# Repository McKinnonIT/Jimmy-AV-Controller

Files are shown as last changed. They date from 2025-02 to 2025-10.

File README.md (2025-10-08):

# Jimmy AV Controller

## 🧩 Project Overview  
The Jimmy AV Controller is an open, customizable solution for projector and AV control over RS232. It is designed to address the limitations of existing commercial systems—closed ecosystems, high costs, poor interfaces, and no easy way to monitor usage and automate groups of projectors & TVs.

It’s designed for use in classrooms, conference rooms, and anywhere you want RS232 control over AV equipment.  
With touchscreen ESP32 boards like the JC2432W328 (capacitive) and 2432S028R (resistive), which support native LVGL in ESPHome, we built a customizable, user-friendly control panel that integrates easily with ESPHome and Home Assistant.  
We chose ESPHome for its popularity and maintainability, with many examples and community support already available.

<p align="center">
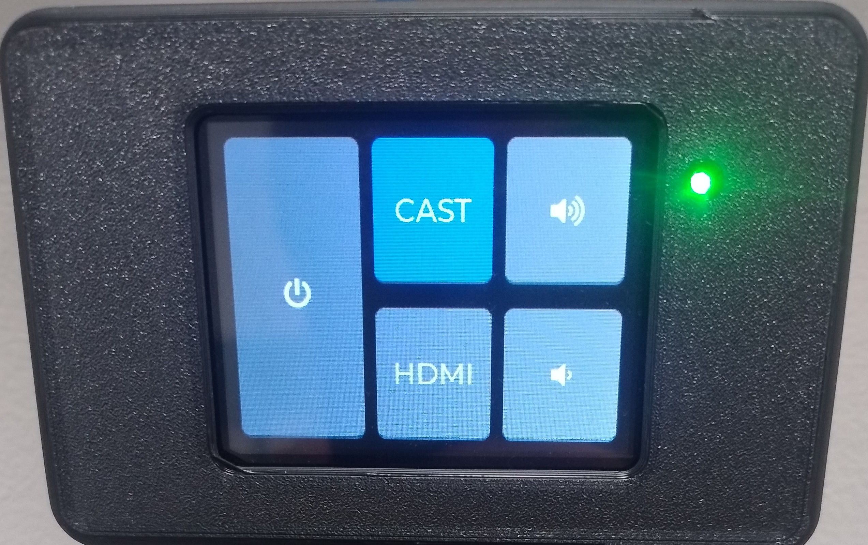
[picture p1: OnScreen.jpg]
  
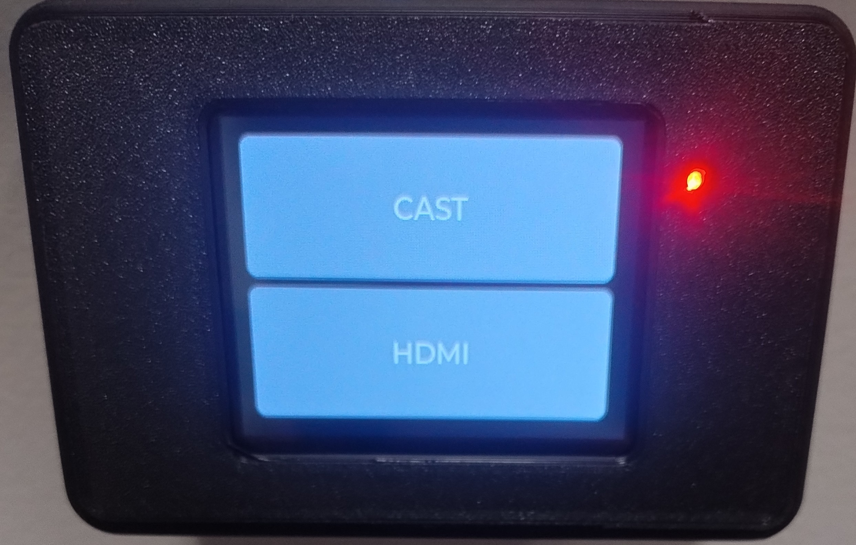
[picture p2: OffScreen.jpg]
  
</p>

## 🧠 How it works

The Jimmy AV Control System uses an ESP32 touchscreen panel to send RS232 commands to AV gear, integrating seamlessly with ESPHome and Home Assistant for easy automation and monitoring.

At its core, the system includes:
- ESP32 touchscreen (capacitive JC2432W328 or resistive 2432S028R) flashed with ESPHome
- LVGL customisable GUI
- 3D-printed wall plate & breakout box for secure mounting  
- RS232 to TTL UART breakout box  
- RJ45 Ethernet cables to connect breakout box to wall plate touchscreen  
- Generic DC power supply  

Using the ESPHome Web Flasher makes setup simple.

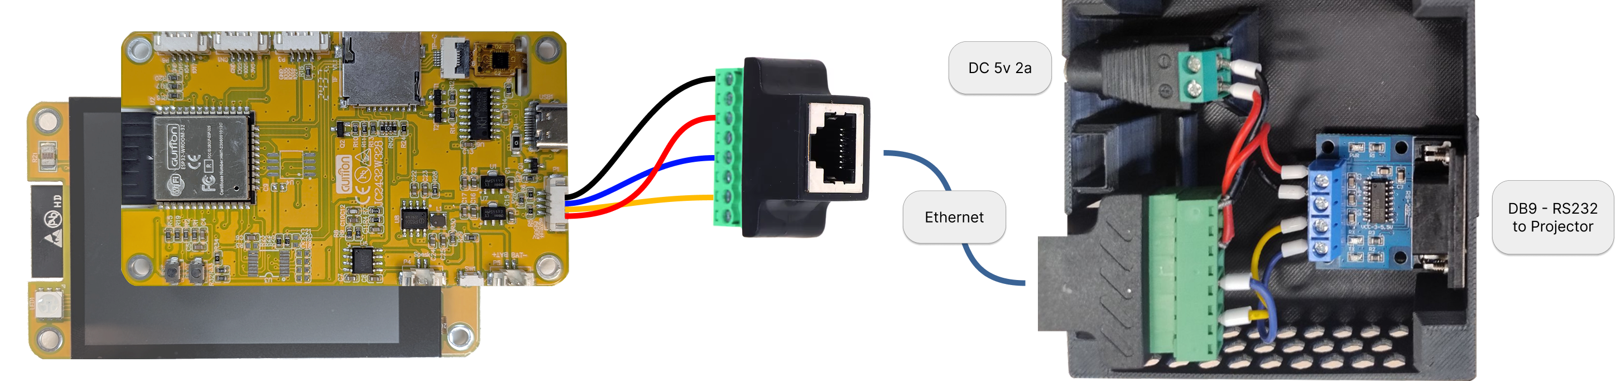
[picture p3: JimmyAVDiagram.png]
System Diagram


## ⚙️ Parts
- ESP32-JC2432W328 or ESP32-2432S028R (CYD)
- RS-232 to TTL UART Module
- RJ45 Screw Terminal adapters x2
- Female DC 5.5 2.1mm terminal adapter
- DC 5v 2A power adapter
- Electrical Wire 20AWG
- 20 AWG Ferrules
- M2.5 10mm Screws
- RJ45 cable (run from wall plate location to projector)
- 3D Printed Wall Plate and Cover (designed for AU Wall Plate standards)
- 3D Printed Breakout Box

## 🛠️ Installation

1. Wire JST cable to RJ45 terminal and plug into the flashed touchscreen  
2. Wire the female DC terminal adapter, RS232 TTL module, and RJ45 terminal block; secure inside the breakout box  
3. Mount the 3D-printed wall plate, connect Ethernet, screw in touchscreen, and snap on the wall plate cover  
4. Place the breakout box in a secure spot, connect the DB9 to projector, plug in Ethernet and power  

## 💾 Flashing Touchscreen

### 🔌 Using ESPHome

Make sure `capacitive.yaml`, `resistive.yaml`, `lvgl.yaml`, and `epsonswitch.yaml` are in the `esphome/common` directory.

1. Connect the touchscreen via USB-C  
2. In ESPHome, create a new device, name it, and select the USB serial port  
3. Modify the config to include secrets and relevant YAML files:

```yaml
    esphome:  
      name:  
      friendly_name:  

    esp32:  
      board: esp32dev  
      framework:  
        type: arduino  

    logger:  
      level: NONE  

    api:  
      encryption:  
        key: ""  

    ota:  
      - platform: esphome  
        password: !secret otapassword  

    wifi:  
      ssid: !secret wifi_ssid  
      password: !secret wifi_password  

    <<: !include common/capacitive.yaml  
    <<: !include common/lvgl.yaml  
    <<: !include common/epsonswitch.yaml  
```
4. Flash this config to the touchscreen. The display should now be interactive.

### 🌐 Standalone using ESPHome Web

Use this if Wi-Fi or Home Assistant isn’t needed.

1. Visit https://web.esphome.io  
2. Connect USB and click **Connect**  
3. Click **Install** and flash `jimmy-av-controller.factory.bin` or a custom `.bin`  

## 🖨️ 3D Printed Parts

This project includes custom 3D-printed enclosures to provide a clean and secure installation:

### 🧱 Included `.stl` Files:
- `lcd-wallplate.stl` – Main mounting frame for the ESP32 touchscreen  
- `lcd-wallplate-cover.stl` – Snap-on faceplate cover for a polished finish
- `breakout-box.stl` – Compact enclosure for RS232, DC, and RJ45 connectors  
<p align="left">
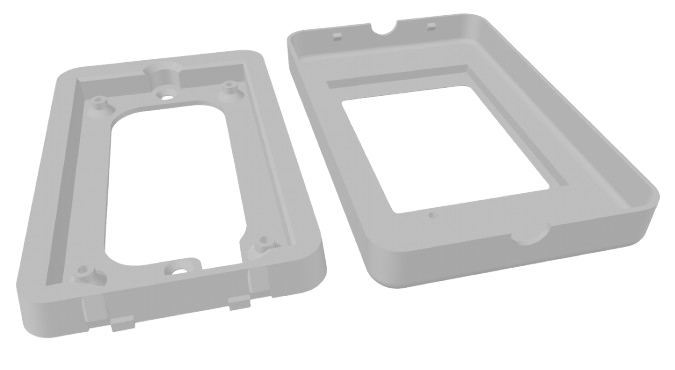
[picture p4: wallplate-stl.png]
  
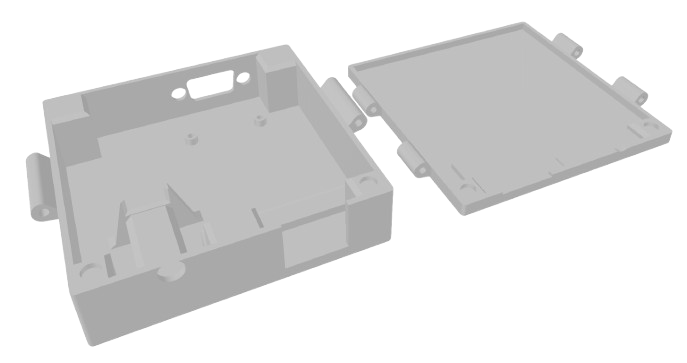
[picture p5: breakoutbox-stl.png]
  
</p>

### 📝 Printing Notes:
- Standard **PLA settings** were used  
- The **breakout box** may require **supports**, depending on your printer and orientation  
- Successfully printed on:
  - **Creality K1C**
  - **Bambu Lab P1S**

> Parts were designed for ease of assembly and professional installation appearance.

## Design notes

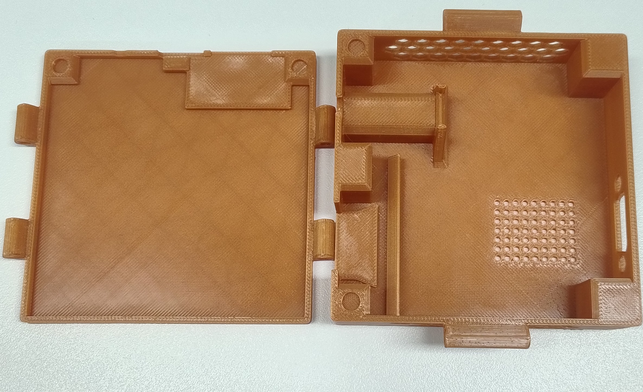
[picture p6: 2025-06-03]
breakoutbox.png

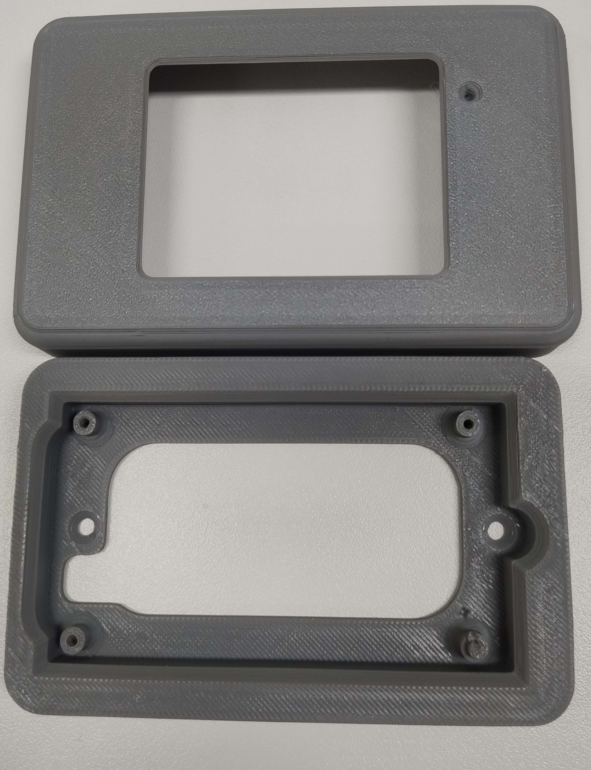
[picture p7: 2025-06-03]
wallplate.png

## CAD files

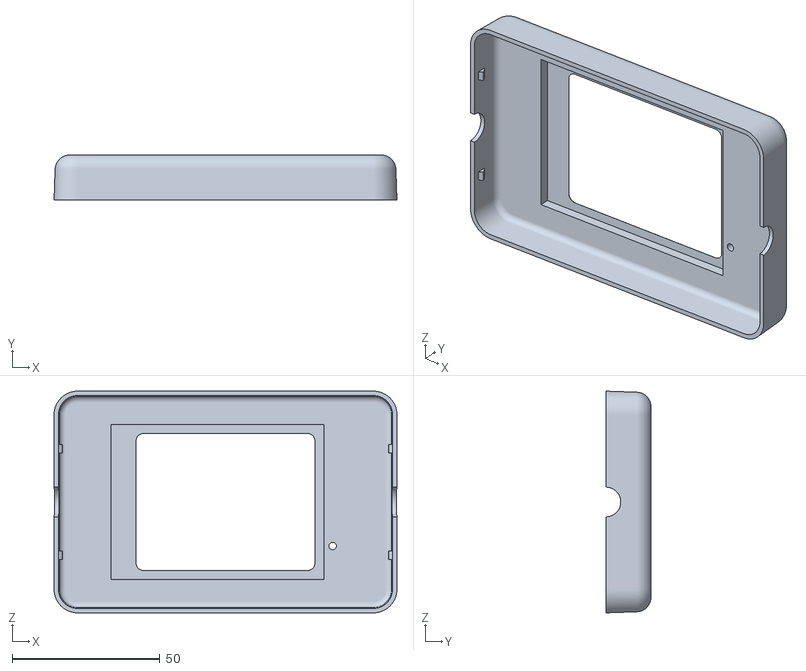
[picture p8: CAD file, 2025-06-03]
lcd-wallplate-cover-07-05-25.STL
116.0 x 15.2 x 75.0

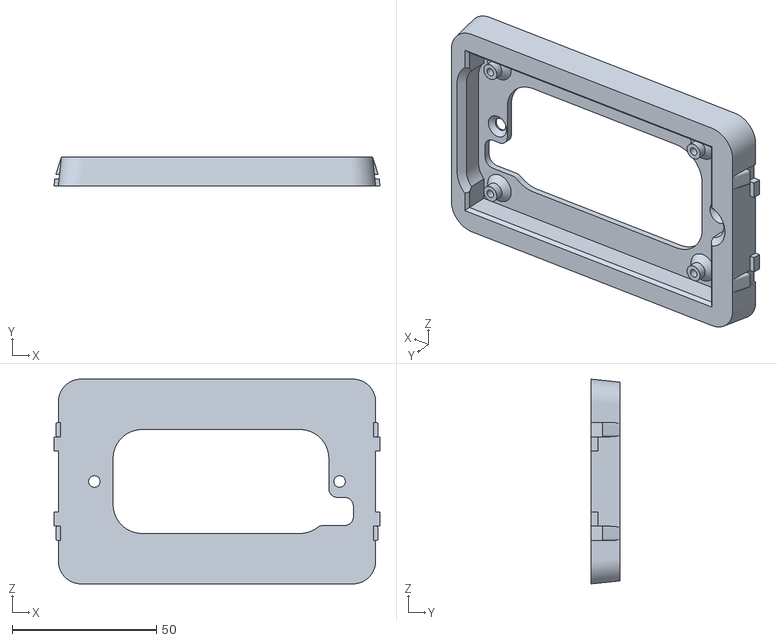
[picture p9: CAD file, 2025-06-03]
lcd-wallplate-07-05-2025.STL
113.0 x 10.0 x 71.0

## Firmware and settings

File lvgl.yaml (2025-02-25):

# Configure LVGL
lvgl:
  displays:
    - my_display
  buffer_size: 0.25
  touchscreens:
    - my_touch
  bg_color: 0x000000
  border_color: 0x000000 
  outline_color: 0x000000
  default_font: montserrat_22
  theme:
    button:
      bg_color: 0x808080
      pressed:
        border_color: 0xFFFF00
      checked:
        border_color: 0xFFFF00
  pages:
    # Default Page displayed
    - id: off_page
      widgets:
        - buttonmatrix:
            x: 0
            y: 0
            width: 320
            height: 240
            bg_color: 0x000000
            border_color: 0x000000 
            outline_color: 0x000000 

            id: matrix_off
            one_checked: true
            items:
              bg_color: 0x808080
              text_color: 0xFFFFFF
            rows:
              - buttons:
                - id: button_cast
                  text: "CAST"
                  on_press:
                    if:
                      condition:
                        binary_sensor.is_on: powerstate
                      then:
                        - lvgl.page.next:
                        - switch.toggle: projectorpoweron
                        - switch.toggle: projectorhdmi1

                      else:
                        - lvgl.page.next:
                        - switch.toggle: projectorpoweron
                        - delay: 10s
                        - switch.toggle: projectorhdmi1
                  on_release:
                      - switch.toggle: projectorpoweron
                      - switch.toggle: projectorhdmi1
                      - lvgl.widget.update:
                          id: btn_cast
                          state:
                            checked: true
                      - binary_sensor.template.publish:
                          id: powerstate
                          state: ON

              - buttons:
                - id: button_hdmi
                  text: "HDMI"
                  on_press:
                    if:
                      condition:
                        binary_sensor.is_on: powerstate
                      then:
                        - switch.toggle: projectorpoweron
                        - switch.toggle: projectorhdmi2
                        - switch.toggle: projectorpoweron
                        - lvgl.widget.update:
                            id: btn_hdmi
                            state:
                              checked: true
                        - lvgl.page.next:
                      else:
                        - lvgl.page.next:
                        - lvgl.widget.update:
                            id: btn_hdmi
                            state:
                              checked: true
                        - switch.toggle: projectorpoweron
                        - delay: 10s
                        - switch.toggle: projectorhdmi2
                  on_release:
                      - switch.toggle: projectorpoweron
                      - switch.toggle: projectorhdmi2
                      - binary_sensor.template.publish:
                          id: powerstate
                          state: ON
    # Page when projector turned on
    - id: on_page
      widgets:
      # Power OFF Button
        - button:
           x: 10
           y: 10
           width: 100
           height: 220
           id: btn_off
           on_press:
              - switch.toggle: projectorpoweroff
              - lvgl.page.next:
              - lvgl.widget.update:
                  id: btn_hdmi
                  state:
                    checked: false
              - lvgl.widget.update:
                  id: btn_cast
                  state:
                    checked: false
           on_release:
              - delay: 500ms
              - binary_sensor.template.publish:
                  id: powerstate
                  state: OFF
           widgets:
            - label:
                align: center
                text: "\uF011"

        # First row of the 2x2 grid
        - button:
            x: 120
            y: 10
            width: 90
            height: 100
            id: btn_cast
            checkable: true
            on_press:
              if:
                condition:
                  binary_sensor.is_on: powerstate
                then:
                  - switch.toggle: projectorpoweron
                else:
                - switch.toggle: projectorpoweron
                - delay: 10s
                - switch.toggle: projectorhdmi1

            on_release:
            - lvgl.widget.update:
                id: btn_hdmi
                state:
                  checked: false
            - lvgl.widget.update:
                id: btn_cast
                state:
                  checked: true
            - binary_sensor.template.publish:
                id: powerstate
                state: ON
            - switch.toggle: projectorhdmi1
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

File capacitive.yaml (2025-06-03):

# Set up global varible to track recent touch
globals:
  - id: recent_touch
    type: bool
    restore_value: no
    initial_value: "true"

# Set up backlight
light:
  - platform: monochromatic
    output: backlight_pin
    name: Display Backlight
    id: backlight
    restore_mode: ALWAYS_ON
# Set up the LED on the back and turn it off by default
  - platform: rgb
    name: LED
    id: led
    red: output_red
    green: output_green
    blue: output_blue
    restore_mode: ALWAYS_OFF

# Configure UART pins and set required baud rate
uart:
  tx_pin: GPIO1
  rx_pin: GPIO3
  baud_rate: 9600

# Setup binary sensor template
binary_sensor:

  - platform: template
    name: powerstate
    id: powerstate
    publish_initial_state: true
    on_press:
      # Power is ON, flash green for 5 seconds, then stay green
      - repeat:
          count: 25
          then:
            - light.turn_on:
                id: led
                red: 0%
                green: 100%
                blue: 0%
            - delay: 500ms
            - light.turn_off:
                id: led
            - delay: 500ms
      # After 5 seconds, keep the LED green
      - light.turn_on:
          id: led
          red: 0%
          green: 100%
          blue: 0%
    
    on_release:
      # Power is OFF, flash red for 5 seconds, then stay red
      - repeat:
          count: 5
          then:
            - light.turn_on:
                id: led
                red: 100%
                green: 0%
                blue: 0%
            - delay: 500ms
            - light.turn_off:
                id: led
            - delay: 500ms

      # After 5 seconds, keep the LED red
      - light.turn_on:
          id: led
          red: 100%
          green: 0%
          blue: 0%

# Setup SPI for the display.
spi:
  - id: tft
    clk_pin: GPIO14
    mosi_pin: GPIO13
    miso_pin: GPIO12

# Setup i2c bus for capacitive touch
i2c:
  sda: 33
  scl: 32  
  scan: true
  id: bus_a

# Setup a pin to control the backlight and channels for the red/green/blue of the LED
output:
  - platform: ledc
    pin: GPIO27
    id: backlight_pin
  - platform: ledc
    id: output_red
    pin: GPIO4
    inverted: true
  - platform: ledc
    id: output_green
    pin: GPIO16
    inverted: true
  - platform: ledc
    id: output_blue
    pin: GPIO17
    inverted: true

#

interval:
    # Every 30 seconds check for recent touch
    # dim the backlight to 50% if not
  - interval: 30s
    then:
      - if:
          condition:
            lambda: |-
                return !id(recent_touch);
          then: 
            - light.control:
                id: backlight
                brightness: 50%
          else:
            - lambda: |-
                id(recent_touch) = false;


# Configure Display in landscape mode
display:
  - platform: ili9xxx
    id: my_display
    model: ST7796
    spi_id: tft
    cs_pin: GPIO15
    dc_pin: GPIO2
    invert_colors: false
    dimensions:
      width: 320
      height: 240
    auto_clear_enabled: false
    update_interval: never
    data_rate: 40MHz
    transform:
      swap_xy: true
      mirror_x: false
      mirror_y: true    

# Configure touchscreen driver and calibrate

touchscreen:
  platform: cst816
  id: my_touch
  update_interval: 50ms
  calibration:
    x_min: 0
    x_max: 307
    y_min: 0
    y_max: 244
  transform:
    swap_xy: True
    mirror_x: True
    mirror_y: False
  on_touch:
      then:
        - light.turn_on:
            id: backlight
            brightness: 100%
        - lambda: |-
            id(recent_touch) = true;
        - light.turn_on:
            id: led
            brightness: 70%
